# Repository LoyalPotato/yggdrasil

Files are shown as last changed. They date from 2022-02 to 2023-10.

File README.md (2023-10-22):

<div align="center">
  Yggdrasil
</div>

</br>
</br>

# Welcome

[][cc-by-nc-sa]

This is the home of my first keyboard project that I dubbed `Yggdrasil`.

It's a 36% split keyboard that is tailored to be comfortable to my hand span. You can find the build guide [here](./docs/build.md).

You can view [here](https://www.youtube.com/watch?v=r2uFzhUAN9s) to see it in action.

Here's what it looks like (minus plates)

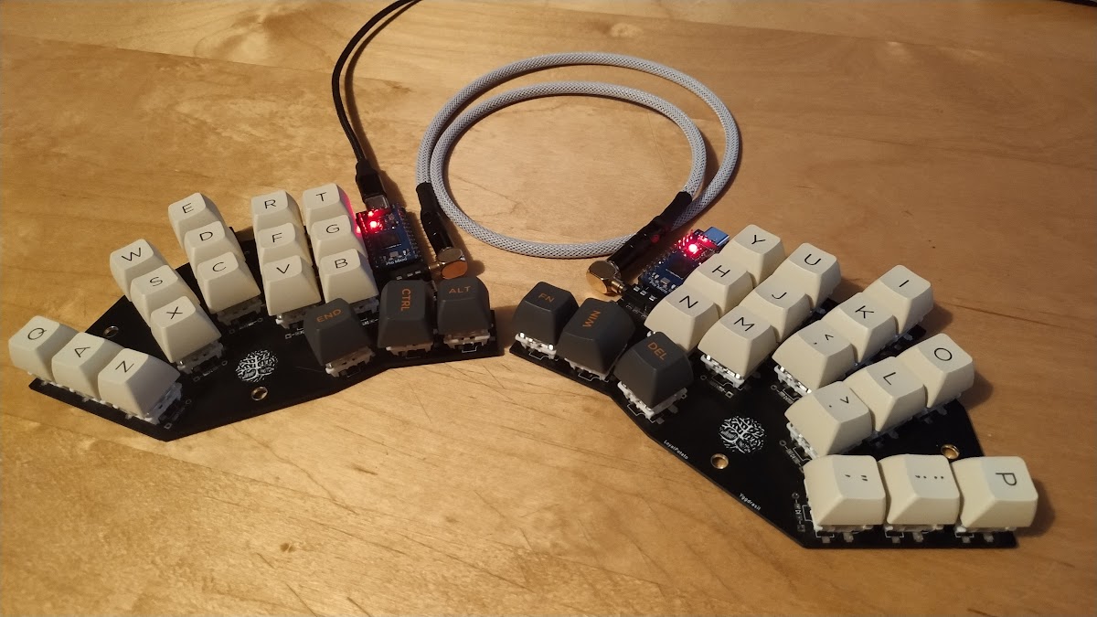
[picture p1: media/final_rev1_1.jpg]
Final


And with 3d printed plates (and custom cables also done by me hehe :) )
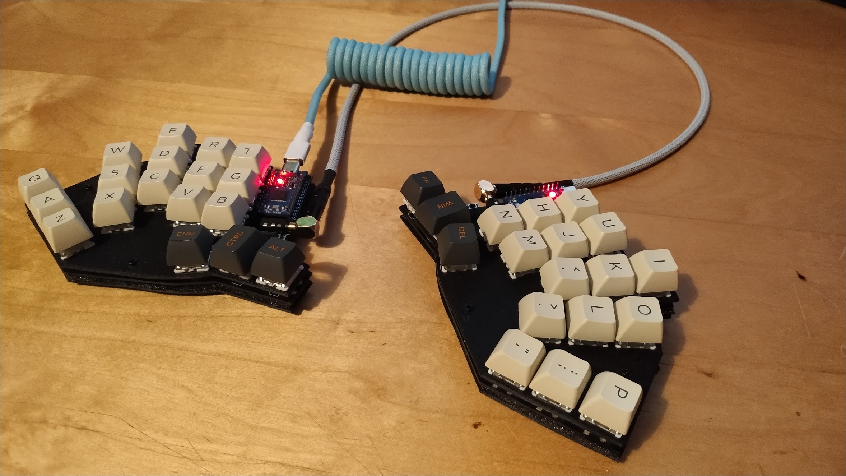
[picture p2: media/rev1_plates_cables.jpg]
Final_v2


Full wrap around case, also 3d printed
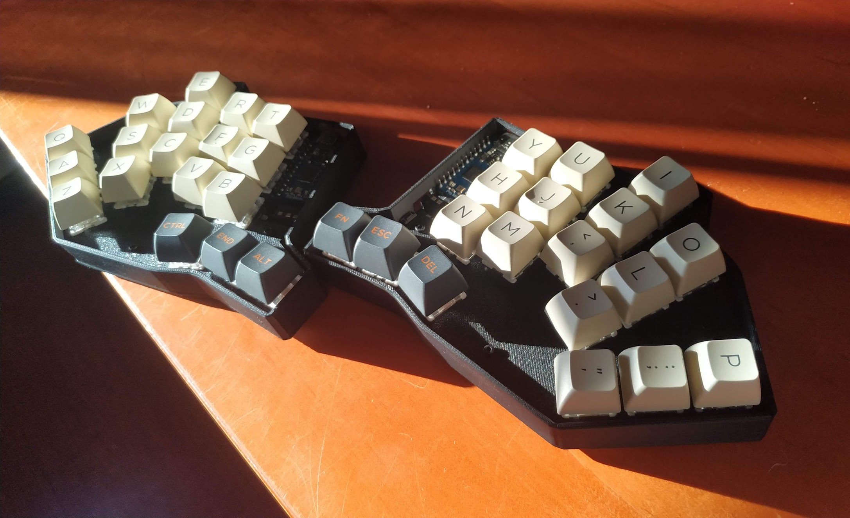
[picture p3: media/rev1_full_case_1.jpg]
Final_full_case

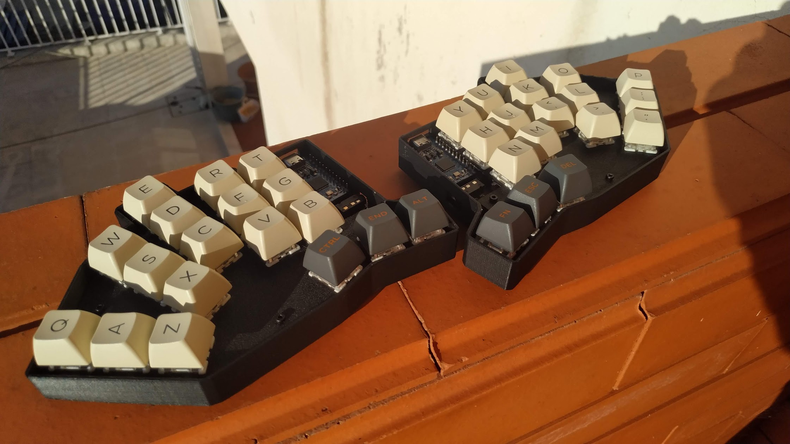
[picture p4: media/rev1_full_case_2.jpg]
Final_full_case_2


## Contents

- [Welcome](#welcome)
  - [Contents](#contents)
  - [Design Article](#design-article)
  - [Plans](#plans)
  - [References](#references)
  - [License](#license)

## Design Article

If you're interested in knowing more about the design process that I went through and the final cost for me (in Portugal), I wrote a [post](https://loyalpotato.com/projects/yggdrasil) about it :)

## Plans

You can go to the projects tab to see what my current plans for the first version of this board are.

~~I do plan on making a low profile kailh choc variant, but only after I complete the cherry variant will I start working on a choc one.~~ I ended up using a footprint that has support for both :)

At some point I also would like to add to each version an alternative with a rotary encoder, and will create separate variants for that as well.

After I get more familiar with the process of pcb design and manufacturing I'd like to have a try at having a modular pcb, like the corne, where we can break the extra keys that you don't need.

---

## References

- [Ergogen](https://github.com/ergogen/ergogen) and the kind people from their [discord](https://discord.gg/nbKcAZB)
- [Ben Vallack's](https://github.com/benvallack/ergogen) flipper ergogen config and his youtube [video](https://www.youtube.com/watch?v=UKfeJrRIcxw)
- [Corne Kbd](https://github.com/foostan/crkbd)
- [ruiqimao's guide](https://github.com/ruiqimao/keyboard-pcb-guide)
- [tapioki's Architeuthis dux](https://github.com/tapioki/cephalopoda/tree/main/Architeuthis%20dux)
- [Lily58](https://github.com/kata0510/Lily58)
- [Keyboard Atelier's Discord](https://discord.gg/b7vwhHS)

## License

This work is licensed under a [Creative Commons Attribution-ShareAlike 4.0 International License][cc-by-nc-sa].

[][cc-by-nc-sa]

[cc-by-nc-sa]: http://creativecommons.org/licenses/by-nc-sa/4.0/
[cc-by-nc-sa-image]: https://licensebuttons.net/l/by-nc-sa/4.0/88x31.png
[cc-by-nc-sa-shield]: https://img.shields.io/badge/License-CC%20BY--NC--SA%204.0-lightgrey.svg

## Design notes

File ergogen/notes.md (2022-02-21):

# Ergogen Files

In this folder you can find several configurations that I iterated on while developing this board. So far the configuration that I ended up following is [this one](./configs/staggered_thumb_spread.yaml). Like mentioned in the plans on the cover of this project, I plan on adding a rotary encoder so that I can have a media controller easily available.

The other files may not be as completed as the one before mentioned due to wanting to spend my time on one design at a time.

## Staggered + Thumb Spread

These are the generated outlines from [this](./configs/staggered_thumb_spread.yaml) config.

### Keycaps Outline

This is what the layout for each key in this format.

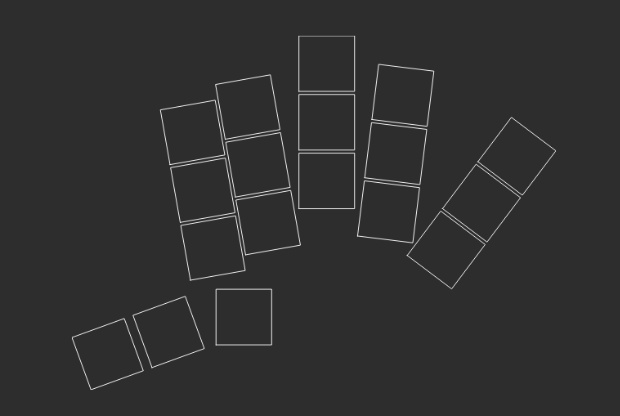
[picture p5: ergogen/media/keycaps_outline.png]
keycaps outline


### Edge Outline

Outline of the whole keyboard, based only on ergogen configuration

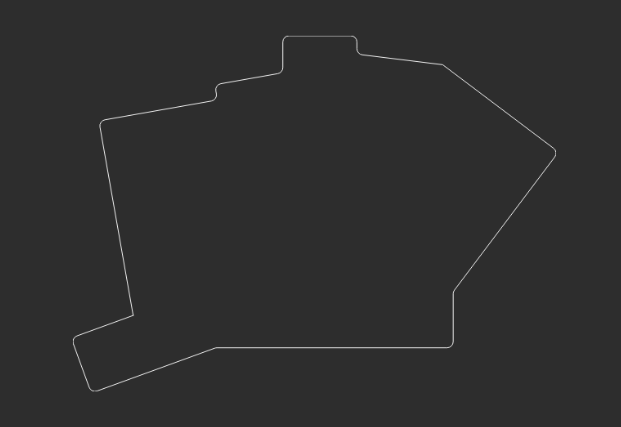
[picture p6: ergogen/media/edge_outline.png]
edge outline


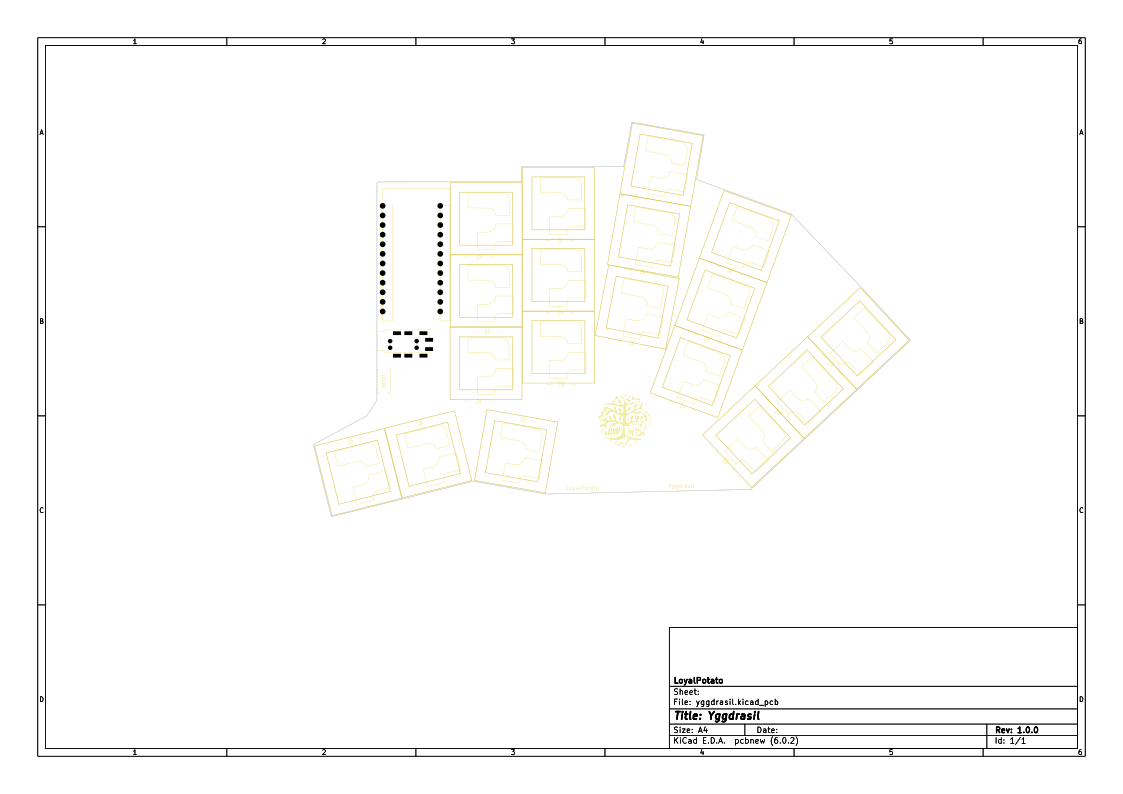
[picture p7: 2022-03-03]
media/yggdrasil_edgecuts_switches.png

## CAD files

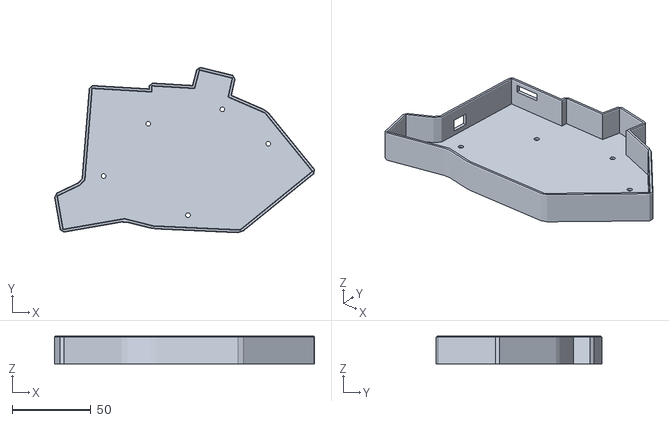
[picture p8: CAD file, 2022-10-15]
plates/rev1/stl_3mf/Yggdrasil Case.stl
164.9 x 105.0 x 17.5

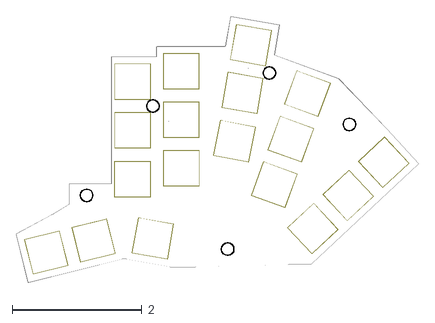
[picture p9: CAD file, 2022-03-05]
plates/rev1/switch_plate.dxf
6.22 x 4.11

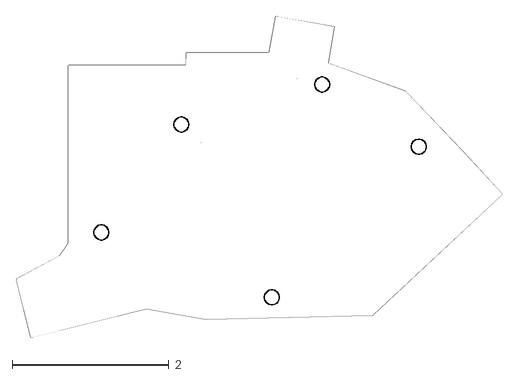
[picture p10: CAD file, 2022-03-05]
plates/rev1/board_plates.dxf
6.22 x 4.11

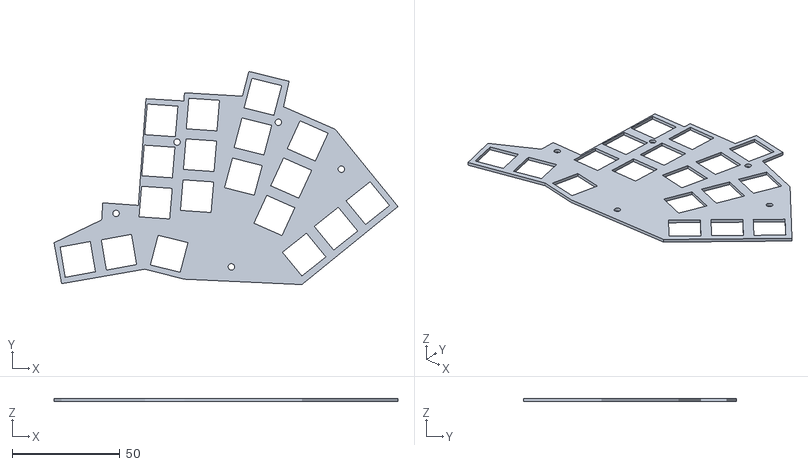
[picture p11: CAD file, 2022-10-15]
plates/rev1/stl_3mf/Yggdrasil Switch Plate.stl
159.6 x 98.9 x 1.40

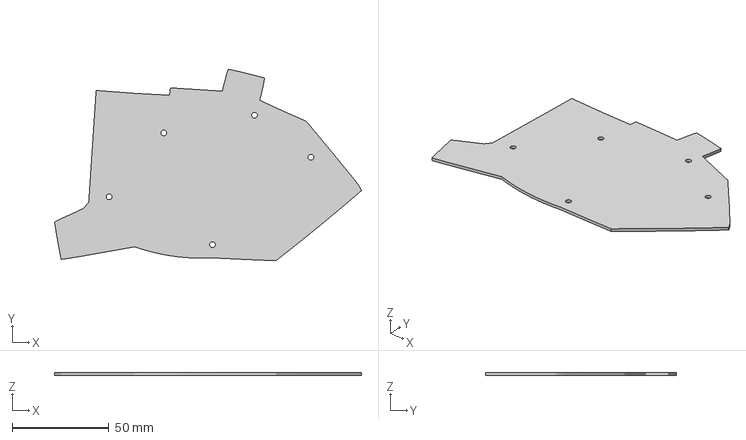
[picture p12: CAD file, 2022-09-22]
plates/rev1/stl_3mf/Yggdrasil Bot Plate.3mf
159.0 x 99.2 x 1.51 mm

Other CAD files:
plates/rev1/f3d/Yggdrasil Case v26.f3d
plates/rev1/f3d/Yggdrasil Switch Plate v10.f3d

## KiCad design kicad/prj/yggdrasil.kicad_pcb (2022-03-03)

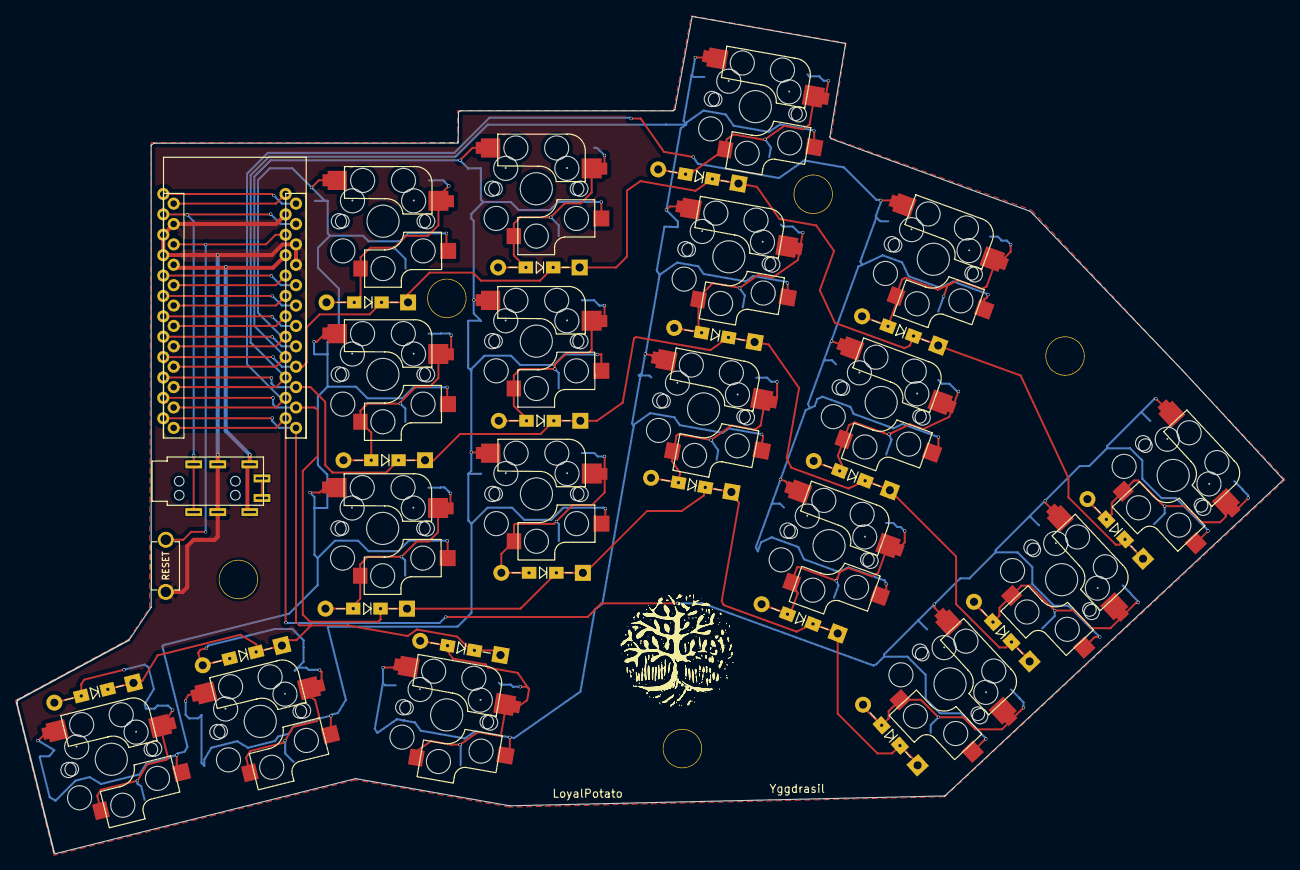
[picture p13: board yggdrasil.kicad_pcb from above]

Board: 2 copper layers, 157.8 x 104.3 mm, 44 parts (0 on the bottom side), 31 nets.

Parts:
D1, D2, D3, D4, D5, D6, D7, D8, D9, D10, D11, D12, D13, D14, D15, D16, D17, D18: D; Diode_TH_SOD123
J2: 4PIN; MJ-4PP-9
RSW1: SW_RST; TACT_SWITCH_TVBP06
SW1, SW2, SW3, SW4, SW5, SW6, SW7, SW8, SW9, SW10, SW11, SW12, SW13, SW14, SW15, SW16, SW17, SW18: SW_PUSH; Cherry_MX_Choc_Hotswap_MX_Spacing
TH3, TH4, TH5, TH6, TH7: HOLE; HOLE_M2_TH
U1: ProMicro; ProMicro_USB_C

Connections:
DATA: J2.3, U1.2 (RX(PD2))
GND: J2.2, RSW1.1, U1.3 (GND), U1.4 (GND), U1.23 (GND)
unnamed: D1.2 (A), SW1.2
unnamed: D2.2 (A), SW2.2
unnamed: D3.2 (A), SW3.2
unnamed: D4.2 (A), SW4.2
unnamed: D5.2 (A), SW5.2
unnamed: D6.2 (A), SW6.2
unnamed: D7.2 (A), SW7.2
unnamed: D8.2 (A), SW8.2
unnamed: D9.2 (A), SW9.2
unnamed: D10.2 (A), SW10.2
unnamed: D11.2 (A), SW11.2
unnamed: D12.2 (A), SW12.2
unnamed: D13.2 (A), SW13.2
unnamed: D14.2 (A), SW14.2
unnamed: D15.2 (A), SW15.2
unnamed: D16.2 (A), SW16.2
unnamed: D17.2 (A), SW17.2
unnamed: D18.2 (A), SW18.2
RESET: RSW1.2, U1.22 (RST)
VCC: J2.1, U1.21 (VCC)
col0: SW1.1, SW6.1, SW11.1, SW16.1, U1.17 (A0(PF7))
col1: SW2.1, SW7.1, SW12.1, SW17.1, U1.16 (D15(PB1))
col2: SW3.1, SW8.1, SW13.1, SW18.1, U1.15 (D14(PB3))
col3: SW4.1, SW9.1, SW14.1, U1.14 (D16(PB2))
col4: SW5.1, SW10.1, SW15.1, U1.13 (D10(PB6))
row0: D1.1 (K), D2.1 (K), D3.1 (K), D4.1 (K), D5.1 (K), U1.9 (D6(PD7))
row1: D6.1 (K), D7.1 (K), D8.1 (K), D9.1 (K), D10.1 (K), U1.10 (D7(PE6))
row2: D11.1 (K), D12.1 (K), D13.1 (K), D14.1 (K), D15.1 (K), U1.11 (D8(PB4))
row3: D16.1 (K), D17.1 (K), D18.1 (K), U1.12 (D9(PB5))

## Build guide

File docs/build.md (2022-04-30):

# Build Guide

This build guide will cover the steps that you need to take in order to build this keyboard.

## Contents

  - [Parts](#parts)
  - [PCB](#pcb)
  - [Hotswap Sockets](#hotswap-sockets)
  - [Diodes](#diodes)
  - [TRRS & Reset Button](#trrs--reset-button)
  - [Micro controller](#micro-controller)
  - [Plates](#plates)
  - [QMK](#qmk)

## NOTE

This is a WIP file. More information will be added as the build progresses

## Parts

| Parts | Quantity | Notes |
| --- | :---: | --- |
| PCB | 2 | Project avaliable [here](/kicad/). I ordered from JLCPCB |
| Plates | (Top + Bottom) * 2 | Go [here](/plates/) and choose the latest revision |
| [USB-C ProMicro](https://www.aliexpress.com/item/1348800135.html) | 2 | Slight length difference from Micro USB ProMicro |
| [TRRS Jacks](https://www.aliexpress.com/item/4000661212458.html) | 2 ||
| [Kailh Hot-swap Sockets](https://www.aliexpress.com/item/4001051840976.html) | 36 ||
| Diodes 1N4148 / 1N4148W | 36 | I used the [SMD](https://www.aliexpress.com/item/32334222067.html) version ||
| [Tact Switch](https://www.aliexpress.com/item/1005001629236725.html)| 2 ||
| [M2 Spacer](https://www.aliexpress.com/item/32974970926.html) | 10 | 6mm|
| [M2 Screw](https://www.aliexpress.com/item/32974970926.html) | 20 | 3mm|
| TRRS Cable | 1 ||
| USB-C Cable | 1 ||
| (Optional) Rubber Feet | Up to you ||

## PCB

For the pcb all you need to do is order two as the pcb is reversible.
I haven't tested compatibility with a regular micro/mini pro micro or the elite-c micro controllers, but the one I mention above works as I designed the pcb with it in mind.
This is what is looks like bare.

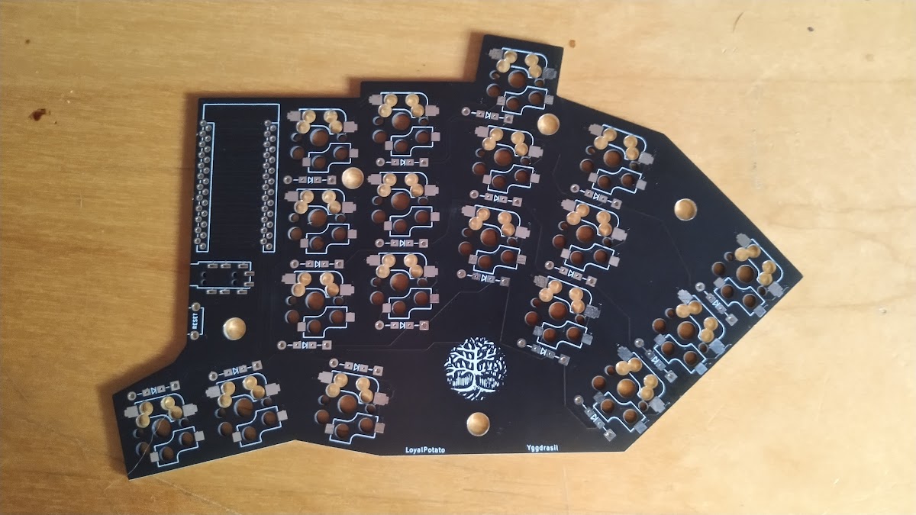
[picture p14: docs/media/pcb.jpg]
pcb


## Hotswap Sockets

This is in no specific order, but the order in which I did mine. But I'd recommend with either starting here or with the diodes and leaving the microcontroller for last.

I started with putting solder in the pads on the respective side, like so:

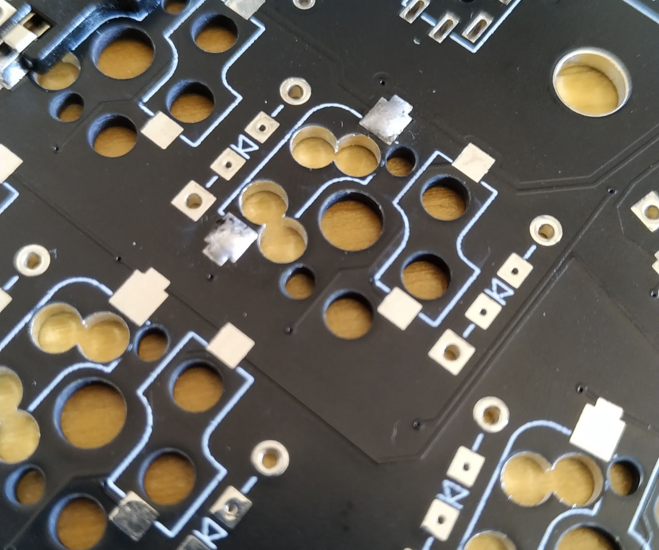
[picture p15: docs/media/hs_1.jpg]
solder


After that is done for all the pads of the hotswap you can procede to the next step which is placing the sockets in they're respective holes.

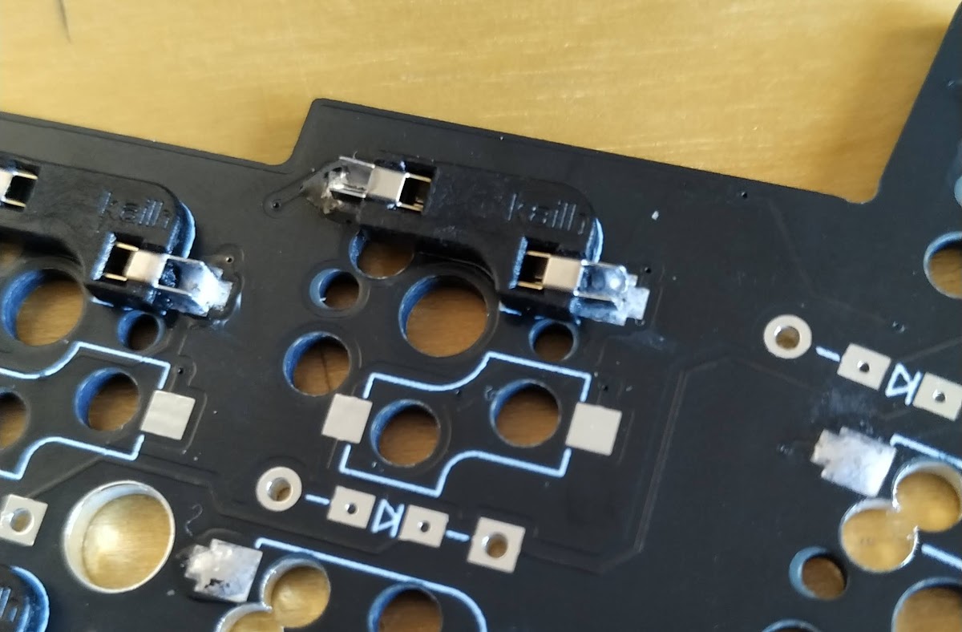
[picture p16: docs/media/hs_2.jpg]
socket placement


A trick that worked for me was placing a tweezer or something similar on the metal part of the socket of the side you are soldering. Then with the iron heat up the pad while pressing with the tweezers down and it should go down. Double check to see if the socket is flush with the pcb.

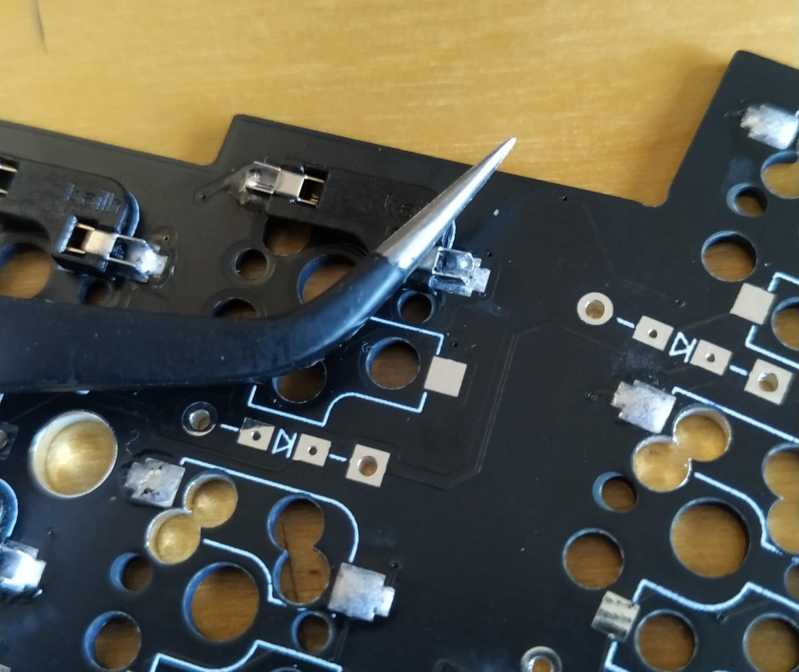
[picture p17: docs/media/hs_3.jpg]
socket placement 1


When you are done with both sides it should look something like this

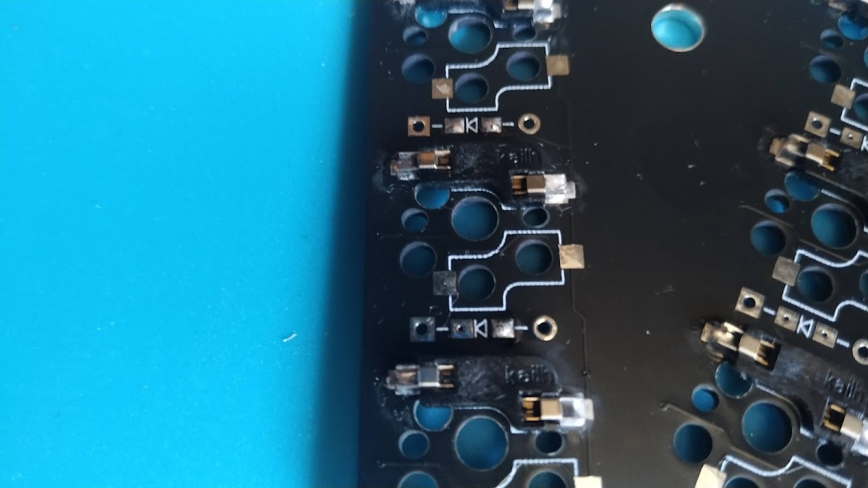
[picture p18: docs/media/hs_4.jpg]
socket placement 2


Repeat the same process for the other side and the rest of the sockets.

## Diodes

The process for the diodes is pretty similar to the process of the sockets.

First you need to check the direction of the diode.
The diode will have one of the sides with a little line to indicate the cathode side, like so:

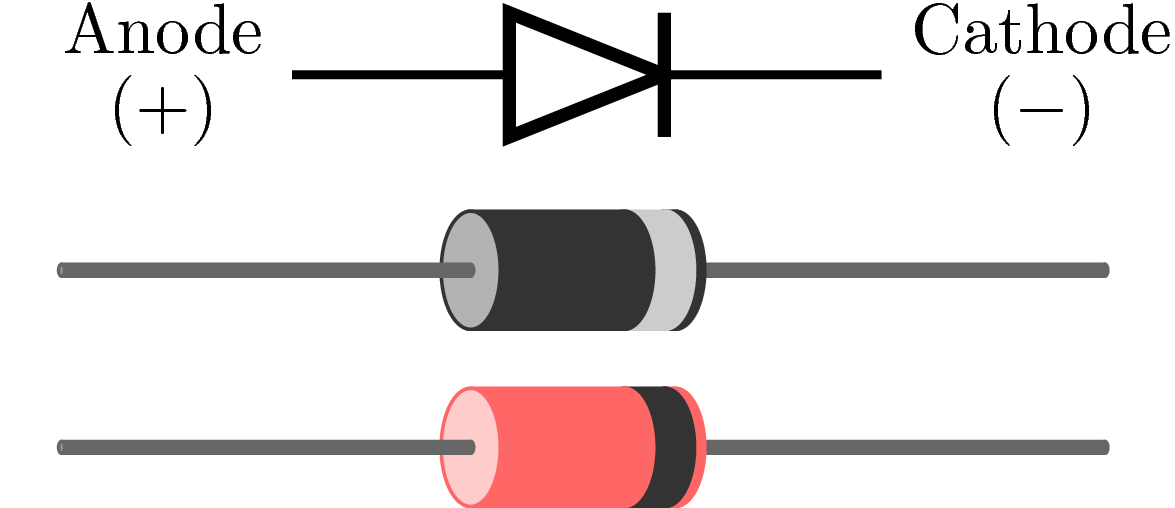
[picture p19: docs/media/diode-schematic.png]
diode schematic


And in the pcb it's marked with the same drawing

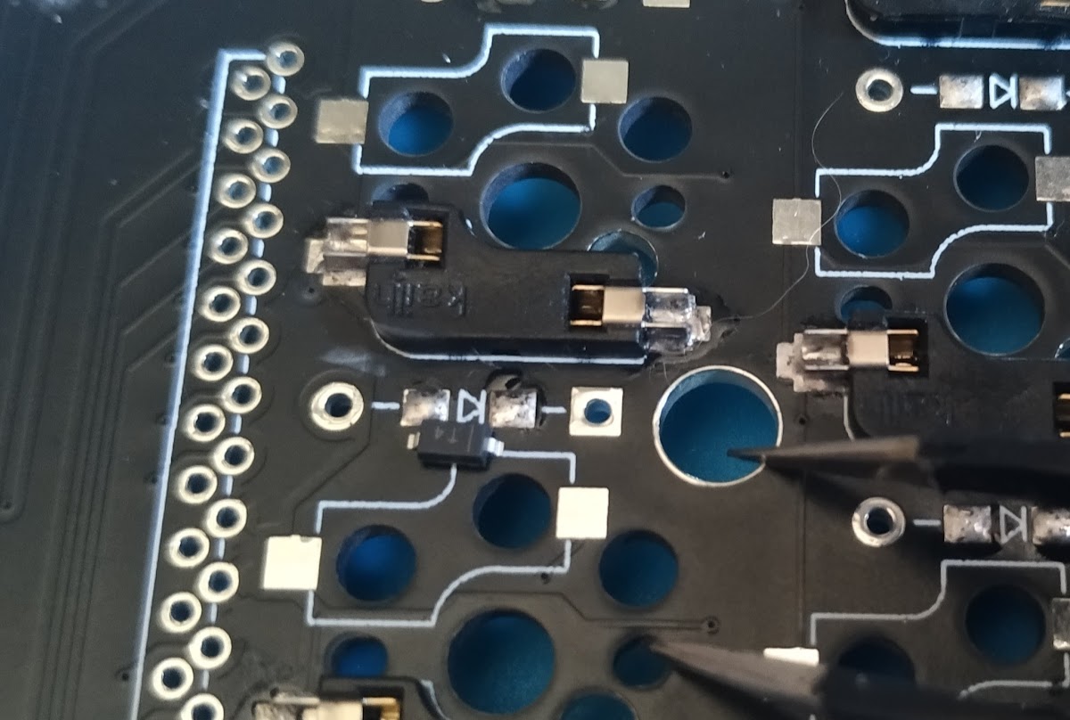
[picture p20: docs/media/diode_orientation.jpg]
diode schematic pcb


For the soldering process, like I mentioned above it's pretty similar to the sockets. First put the solder in the pads, then place the diode with the correct orientation and solder one side. After that solder the other one while putting a slight pressure on the diode. Be very careful with the pressure as you only need a little bit for it to go down.

Make sure that the pron of the diode is fully covered with solder as this can lead to the key not inputting correctly.

After you're done with that you're keyboard halve/halves should look like the following picture, with the sockets soldered as well.

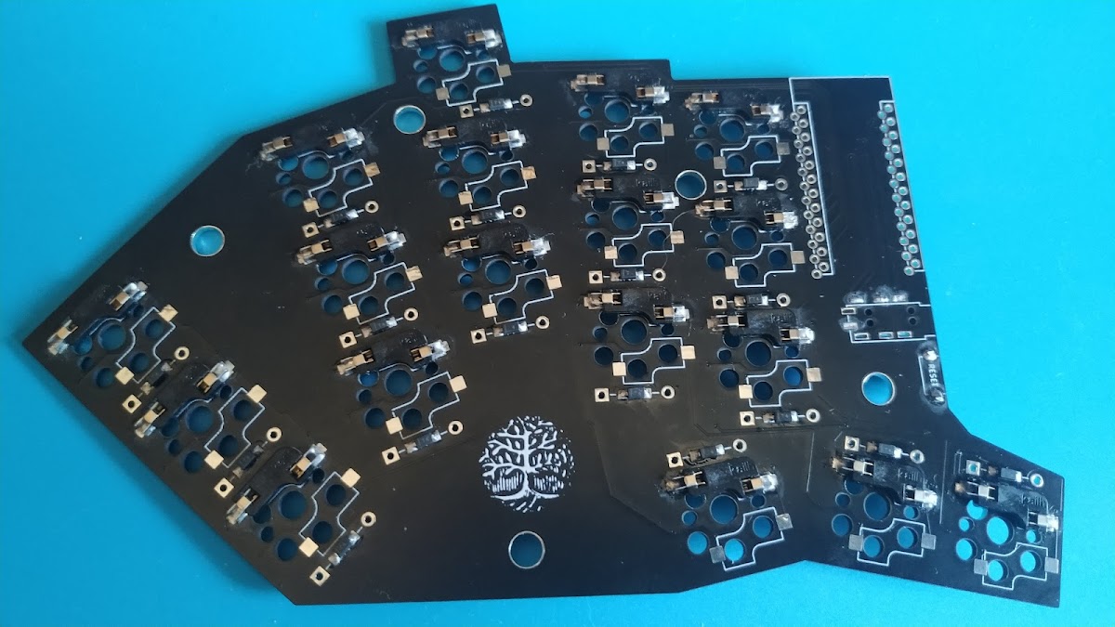
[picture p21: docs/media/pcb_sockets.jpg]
diodes & sockets


## TRRS & Reset Button

I recommend, even though you may see otherwise in the previous pictures, to solder these at the end or before the micro controller as the height difference may cause some issues while soldering the previous components.

These are pretty easy to solder. For the jack, just point it out and solder underneath. And for the reset button it doesn't matter the orientation, but bend the pins or cut them so they are flush (if you find it better to leave as is it's also good).

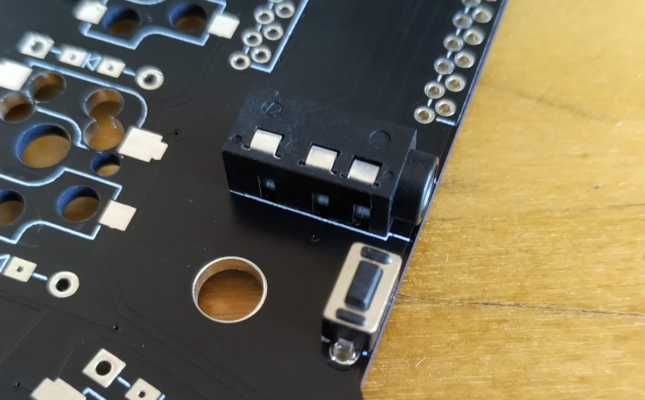
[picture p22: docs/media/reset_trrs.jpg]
button & jack


## Micro controller

The final component that needs to be soldered is the micro controller.

Before soldering though, make sure that it turns on and that you can flash it so that you don't have to go through the pain of desoldering it if something isn't working. You view the flashing process [here](#qmk).

To start first insert the mcu in the correct pins, both of them facing up. You can use the next picture for guidance.

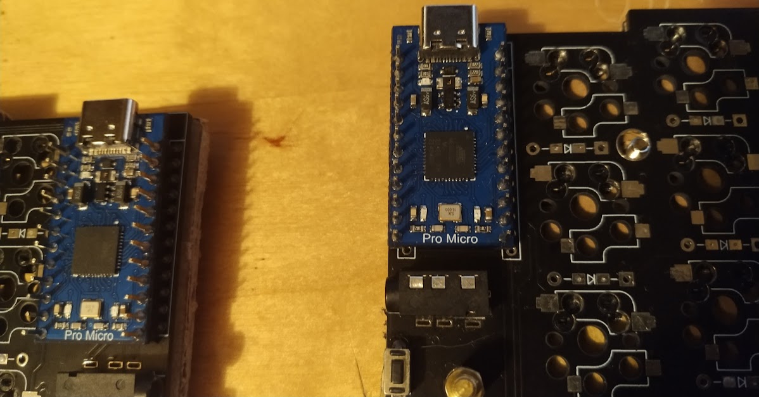
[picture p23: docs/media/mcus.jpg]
mcus orientation


When you've figured out the orientation flip it around and solder each of the pins. 

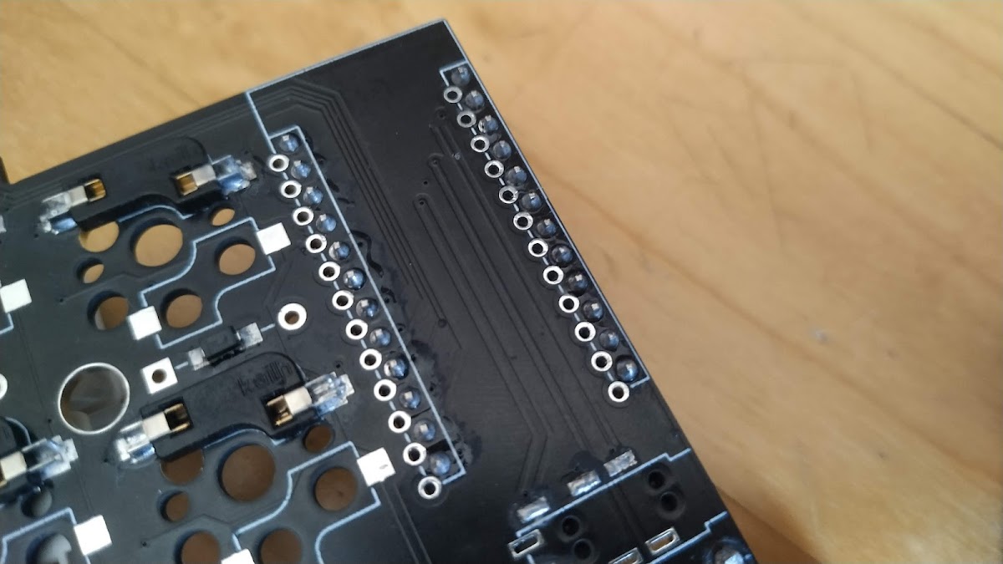
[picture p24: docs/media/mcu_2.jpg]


After that flip it again and solder the pins on the top and you're finished :)

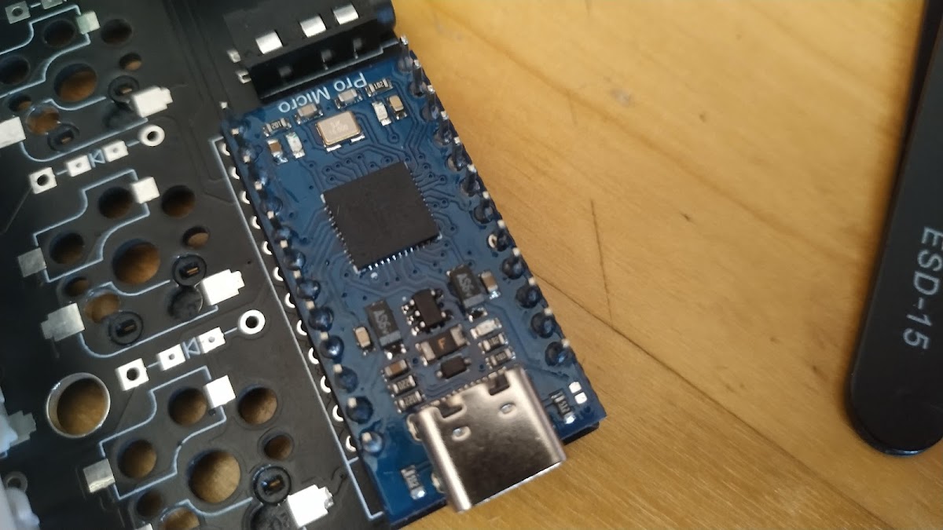
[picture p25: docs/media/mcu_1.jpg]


## Plates

TODO

## QMK

Flashing is also pretty simple. I used QMK as the firmware for my board so I will document only that, for now.

If the keyboard isn't in the official qmk repo the use my [fork](https://github.com/LoyalPotato/qmk_firmware) and procede to the next step.

Follow their [setup guide](https://docs.qmk.fm/#/newbs_getting_started) to get the qmk cli available in you're machine.

Once you have qmk you need to flash the keyboard with the chosen keymap, for example:

```shell
qmk flash -kb loyalpotato/yggdrasil/rev1 -km LoyalPotato
```

And you should have a fully functioning Yggdrasil board :D

Final

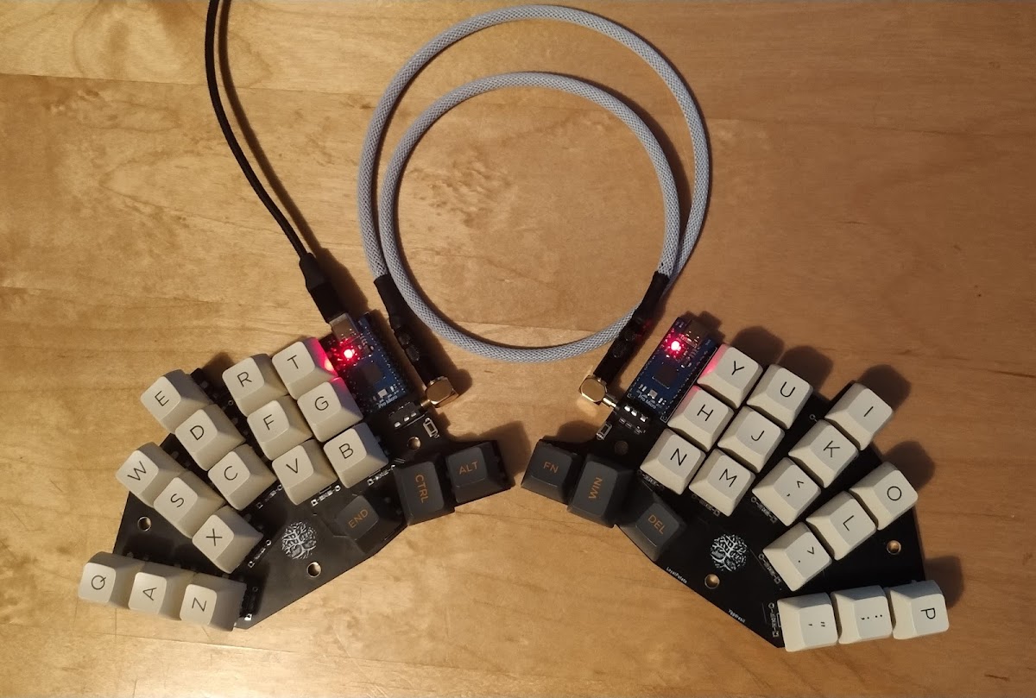
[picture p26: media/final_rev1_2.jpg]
Final 2


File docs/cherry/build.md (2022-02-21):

# Build Guide for the cherry variant of this keyboard

WIP

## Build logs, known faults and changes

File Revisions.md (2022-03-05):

# Revisions

Here is documented the changes that were made from each revision.

## 1.0.1

- Fixed rotation in a switch

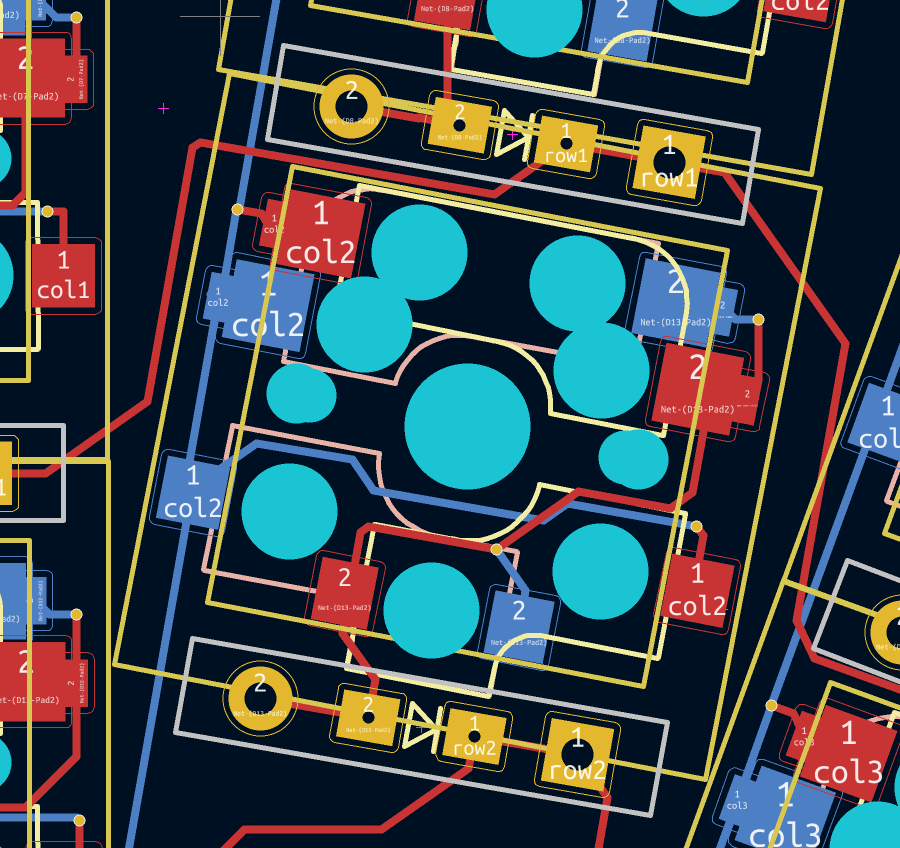
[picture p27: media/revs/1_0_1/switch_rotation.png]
Switch Rotation


- Some spacing fixes

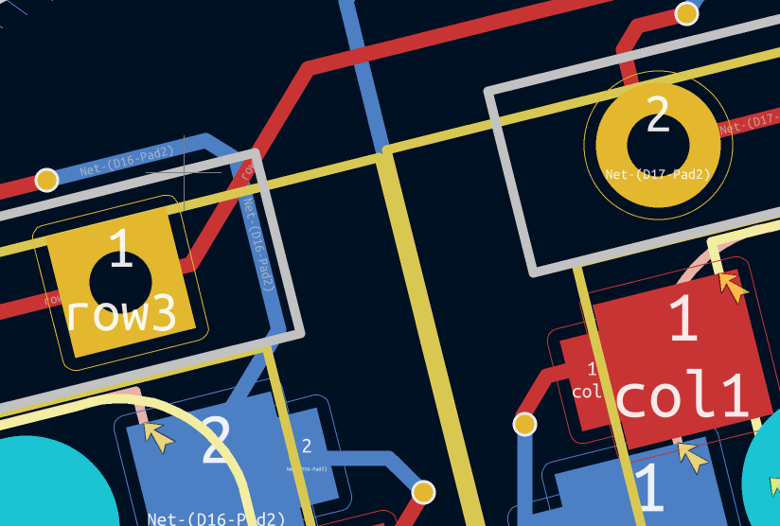
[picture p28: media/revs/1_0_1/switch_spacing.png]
Switch Rotation


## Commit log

2022-02-21 Doc file for choc switches build guide
2022-02-23 Add kicad backup folder to gitignore
2022-02-24 Outlines v1
    [edge_cuts_round.dxf, keycaps.dxf, raw.dxf]
2022-02-28 Lily58 footprints
2022-02-28 kbd footprints
2022-02-28 Kicad project
    [yggdrasil.kicad_pcb, yggdrasil.kicad_sch, yggdrasil_i1c_supported.kicad_sch]
2022-03-01 Add custom footprints Hotswap switch with cherry keycap spacing Different measurements for promicro with usb-c
2022-03-01 Updated spacing Re-do edge cuts Some routing Diode placement Screwhole placement
    [yggdrasil.kicad_pcb, yggdrasil.kicad_sch]
2022-03-02 Logo with and without text in png format for kicad
2022-03-02 Change switch keycap spacing Add routing Add ground plane Add logo & text
    [yggdrasil.kicad_pcb, yggdrasil.kicad_sch]
2022-03-02 Footprint for logo
2022-03-03 Clean up/straighten routings
    [yggdrasil.kicad_pcb]
2022-03-03 Add image with board outline and switch placement
2022-03-03 Kicad prj update
2022-03-03 Add gerber
    [yggdrasil-B_Cu.gbr, yggdrasil-B_Mask.gbr, yggdrasil-B_Paste.gbr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]
2022-03-03 Prj files
    [yggdrasil.kicad_pcb]
2022-03-05 Add plates for first revision Still need to confirm if everything works out
    [board_plates.dxf, switch_plate.dxf]
2022-03-05 Deleted outlines folder as I haven't used it so far
    [edge_cuts_round.dxf, keycaps.dxf, raw.dxf]
2022-03-05 Revision 1.0.1 Fixed wrong rotation, some spacing and clearences
    [yggdrasil.kicad_pcb]
2022-09-13 Add svg plates
2022-09-22 Bot plate, still needs some improvement
    [Yggdrasil Bot Plate v3.3mf]
2022-10-15 Add plates
    [Yggdrasil Bot Plate.3mf, Yggdrasil Case v26.f3d, Yggdrasil Case.stl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]

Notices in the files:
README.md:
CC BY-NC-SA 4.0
